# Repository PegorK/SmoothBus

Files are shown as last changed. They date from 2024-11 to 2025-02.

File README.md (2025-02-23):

<div align="center">
  CoverImage
</div>
<p>

# V2 - 2/23/25
<div align="center">
    <table>
        <tr>
            <td>
                <div align="center">
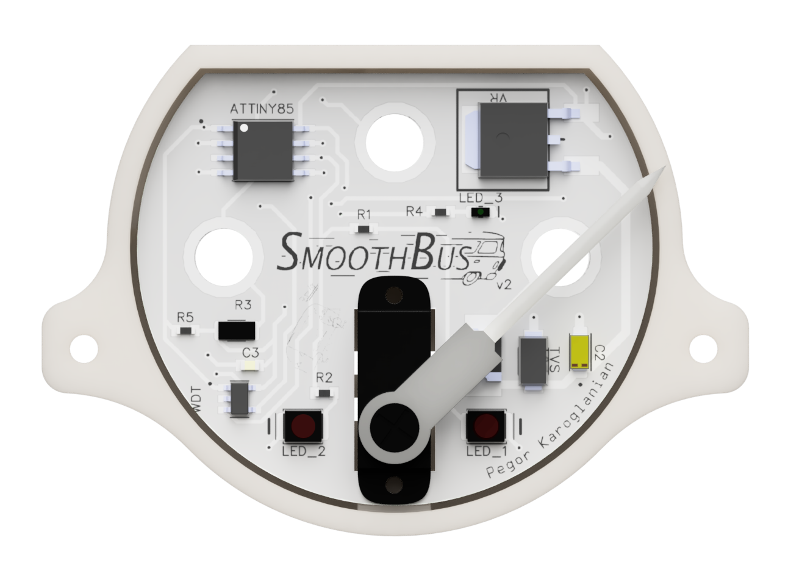
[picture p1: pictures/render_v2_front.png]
V2 Front
                    
                    <br />V2 Front
                </div>
            </td>
            <td>
                <div align="center">
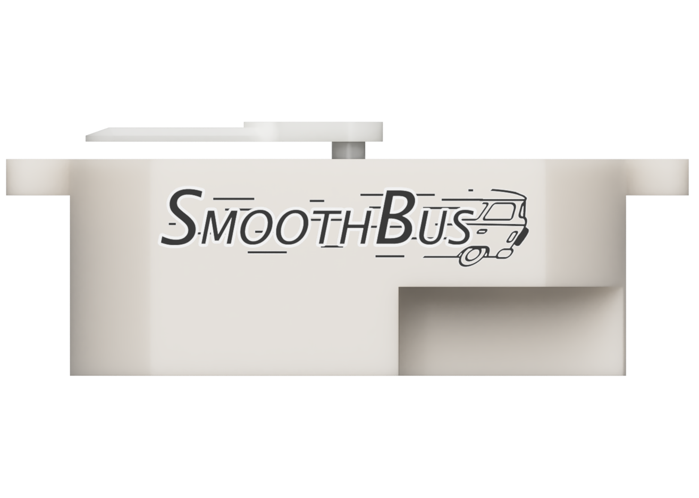
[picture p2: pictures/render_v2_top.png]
V2 Top
                    
                    <br />V2 Top
                </div>
            </td>
            <td>
                <div align="center">
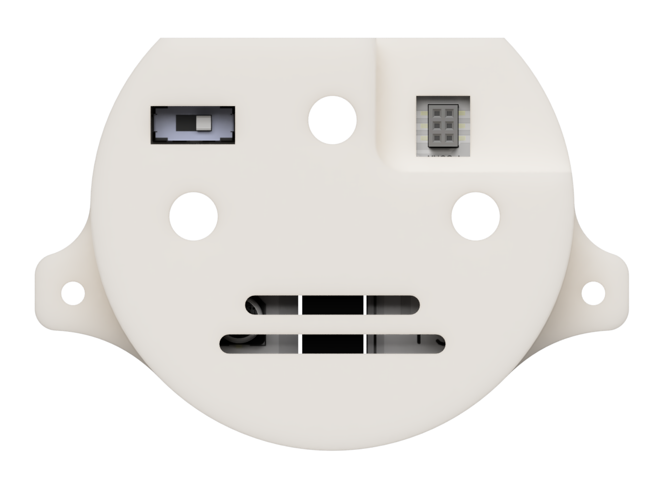
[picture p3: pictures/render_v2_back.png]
V2 Back
                    
                    <br /> V2 Back
                </div>
            </td>
        </tr>
    </table>
</div>

### What's new in V2?
#### Hardware:
* New PCB! Now with input voltage filtering, external watchdog timer, and easier programming connector. 
* Switched to automotive grade ICs (except attiny85, can't find any in stock).
* Reduced voltage divider known resistor value to increase accuracy.
* New 3D printed enclosure to accommodate the new connector, `programming_jig.stl` no longer needed.
#### Software:
* Added new calibration values for fuel sender.
* Added watchdog timer support.
* Increased moving average window size.
* Cleaned up & simplified some chunks of code.
* Removed unused debug.

After getting some feedback on the initial release I decided it was time to put together another build with some improvements that were suggested and also some that I thought would be beneficial. One important change was getting better calibration values from my fuel sender. Previously I was using the data off a forum post that is mentioned below, but I came to realize that my fuel sender (Classic Line 8115800400 from BusDepot) has slightly different readings. I decided to remove it out of the fuel tank and mount it inside a 5 gallon bucket which had lines at the corresponding fuel heights (35mm = R, 75mm = 1/4 tank, 130mm = 1/2 tank, 200mm = Full) and then poured water up to those lines and took multiple readings and averaged them to create the table seen in the code. I left the old values in case it matches someones out there.

In terms of hardware a big improvement is the input voltage filtering, which was completely missing in my original build. Although I didn't run into any power related issues with the first build (at least not for the time I used it), it's better to be safe and this gave me an opportunity to learn a bit more about transient voltages. Speaking of voltages I also upgrade the known resistor R1 in the voltage divider circuit be a lower resistance (50 ohms) and also better rated for the power it's handling. The lower value on this resistor should provide a slightly more accurate reading of the fuel senders position since it's closer to its range. Last new addition I'd like to highlight is the new watchdog timer. I think it's a good failsafe to have in the event there are any funky power glitches that puts the mcu in a bad state. A quick reset from the watchdog in this scenario and we're back up and running and the user wouldn't notice a thing. Hope you enjoy these updates.
<br>
<br>

</p>

<p>

# SmoothBus - 12/4/24
SmoothBus is a fuel gauge conversion for the classic VW Bus. More specifically a 1978 Bus. It's an all in one package with a small form factor that is slightly larger than the original gauge and can be installed with very minimal modifications to the dash. This started as a weekend project after my fuel gauge was showing me readings from all over the place.
</p>
<p>
The original gauges in the buses are pretty clever in design. I've included a picture of it below. It's pretty simple and if my understanding is correct, the flow of current through it causes the wire to heat up and expand which causes the needle to move to different positions. The current is controlled by the fuel sender float which is located in the fuel tank and is essentially a rheostat. Utilizing this thermal property also smooths out bumps and turns since it takes a second or two for it expand & contract. These things don't normally break, it's the voltage regulator that they are connected to that often goes bad, but what's the fun in replacing that when you can make your own.
</p>

<div align="center">
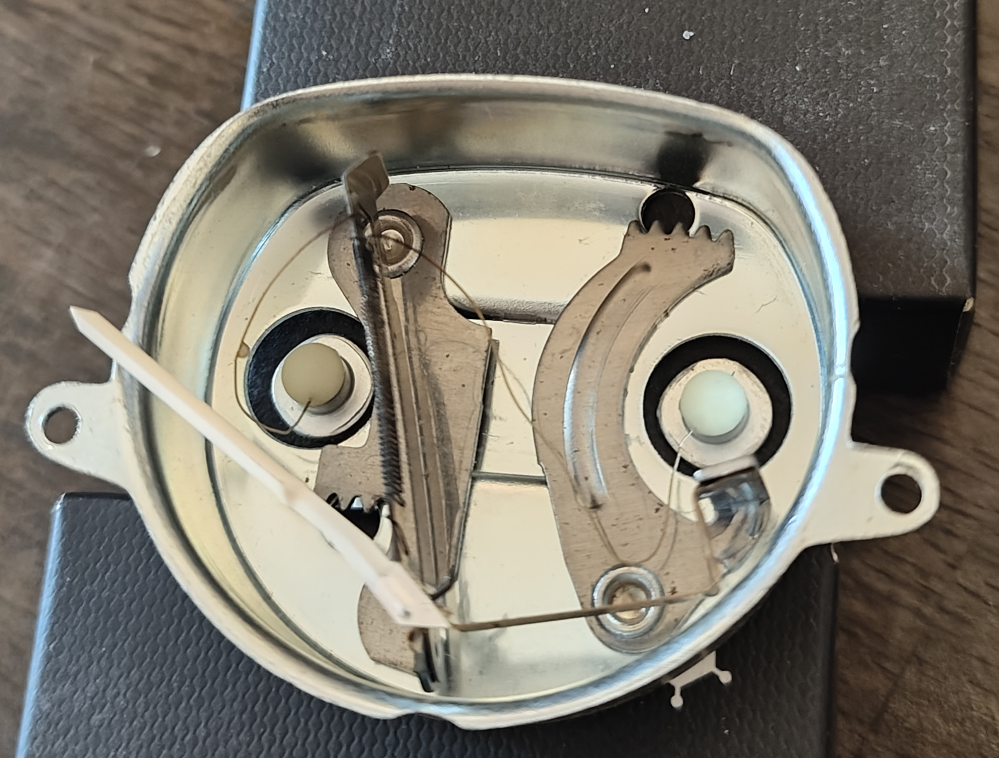
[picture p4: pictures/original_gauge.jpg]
Original fuel gauge
    
    <br />Original fuel gauge guts.
</div>

The SmoothBus design ditches the old gauge components including the voltage regulator keeping only the fuel sender float which is used as the variable resistor in the voltage divider circuit. The overall process is still pretty simple, the ATTiny85 microcontroller reads the analog voltage on one of its input pins and outputs that value as a servo position that corresponds to the location on the original dial. The positions & values were determined by some very useful investigations that were done in this [samba forum post](https://www.thesamba.com/vw/forum/viewtopic.php?t=693930). The analog voltage that gets inputted is the voltage divider circuit that consists of a known resistor value (100ohms) and the unknown resistor value from the fuel sender which ranges from 10 ohms to 79ohms. There is also a moving average that is happening with each read. The configuration that I found works best has been a moving average window of 35 that has readings every 200ms. All of this can be easily changed in the code that can be found in `src` directory. It should be pretty easy to setup, it was all written in the Arduino IDE with the [ATTinyCore](https://github.com/SpenceKonde/ATTinyCore) library that adds support to a bunch of tinyAVR devices (very cool project).

Programming the board wasn't the most intuitive. I decided to have probe points on the board (bottom left corner of PCB) that I thought would be a good idea to easily program the device, but it ended up being a bit finicky. It required making a jig and using tiny spring loaded probes that were then connected to an Arduino Mega that was used as an ISP (see below). [I thought I learned my lesson last time](https://gitlab.com/_Pegor/kepler_fw/-/tree/master/Hardware?ref_type=heads#programming-jig). I think the rest of design is rather straight forward. It contains a voltage regulator that can handle up to 35V and also has some red LEDs to indicate low fuel level. The schematic is included in `hardware/PCB` along with the gerber zip that you can send to a PCB manufacturer of your choice.

<div align="center">
    <table>
        <tr>
            <td>
                <div align="center">
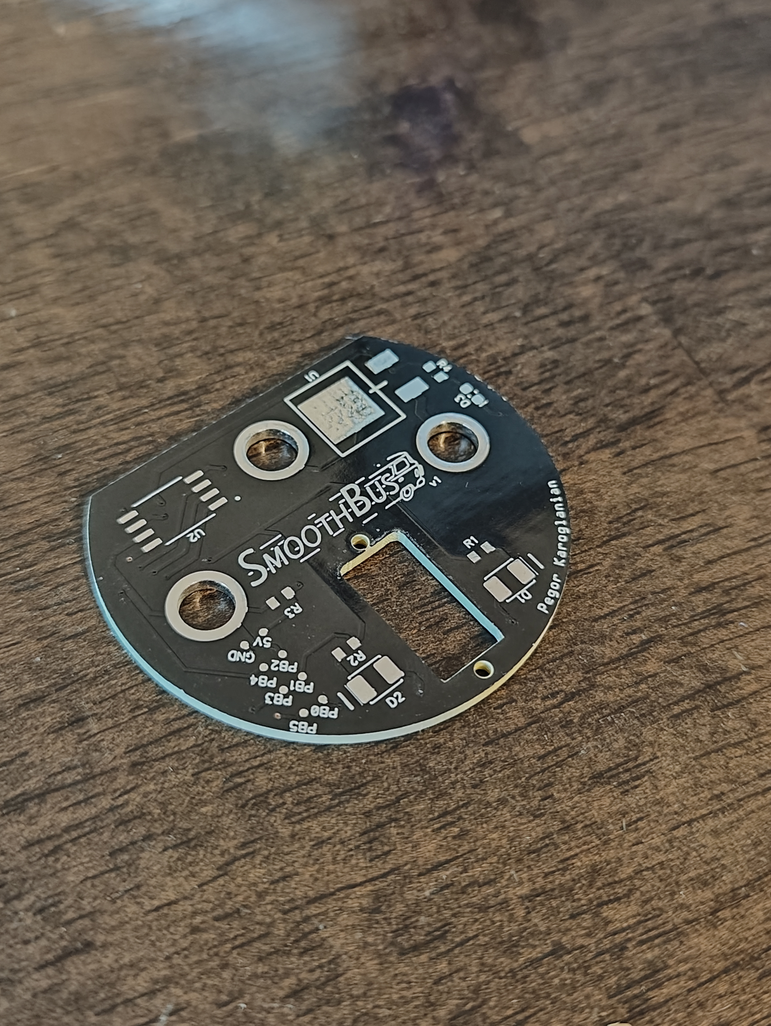
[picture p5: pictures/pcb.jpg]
PCB
                    
                    <br />PCB
                </div>
            </td>
            <td>
                <div align="center">
                    Programming jig
                    <br /> Programming jig
                </div>
            </td>
        </tr>
    </table>
</div>

<div align="center">
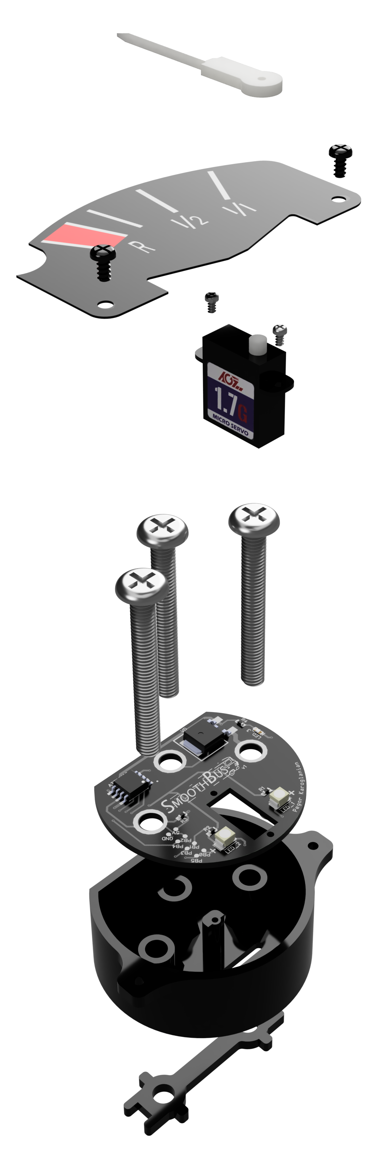
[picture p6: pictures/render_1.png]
Smooth bus render
    
    <br />Render of all the parts.
</div>

I have included all the required 3D parts seen in the render above in the `hardware/3D Parts` directory. Everything was printed in GF-ASA so there is no warping due to warmer temperatures. Installation of the gauge required drilling one hole for the ground screw, other than that there was no other modification required to the dash. You can see it installed below. The red screw is the 12v line, the yellow is for the fuel sender, and the middle is ground, that whole backplate is grounded so no need to run additional wires.

<div align="center">
    <table>
        <tr>
            <td>
                <div align="center">
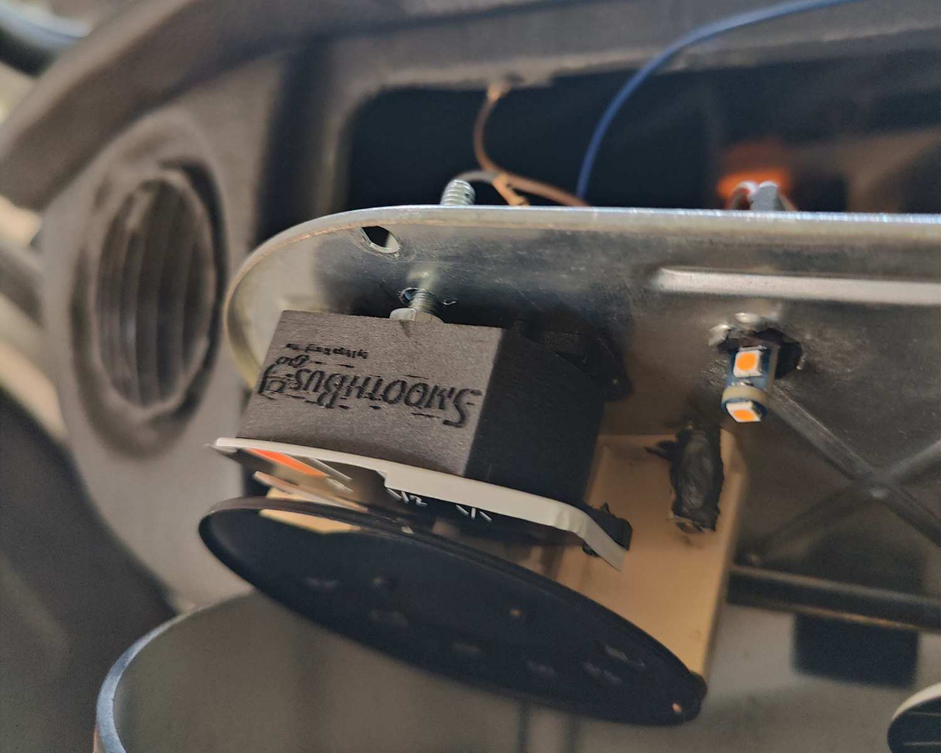
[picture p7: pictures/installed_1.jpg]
Installed Gauge
                    
                    <br />Installed fuel gauge
                </div>
            </td>
            <td>
                <div align="center">
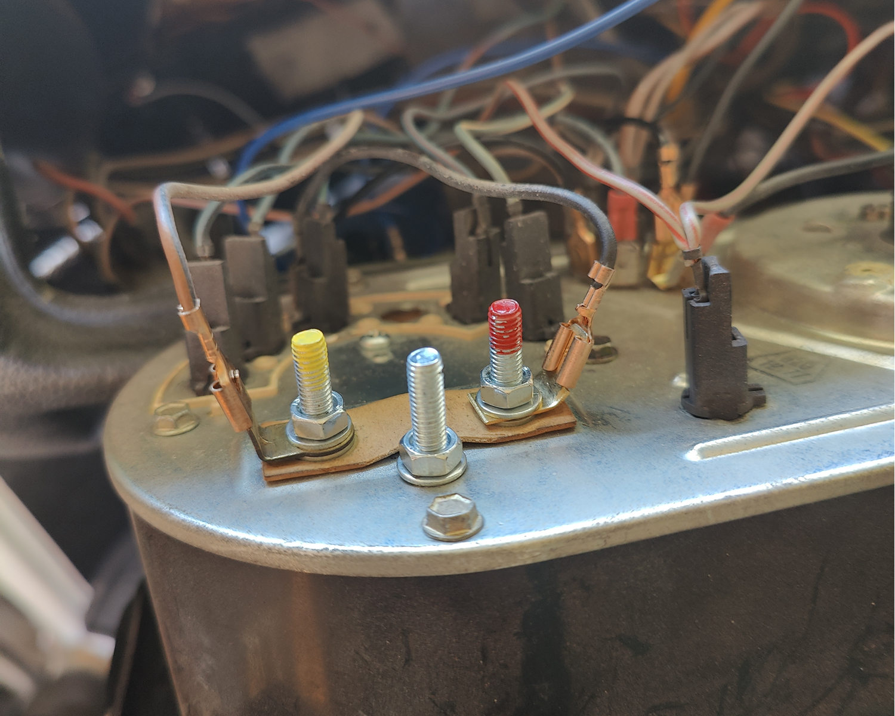
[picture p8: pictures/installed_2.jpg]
Installed Gauge
                    
                    <br /> Terminals of the fuel gauge
                </div>
            </td>
        </tr>
    </table>
</div>

Lastly here is a picture of the finished product and a gif of it in action. Happy tinkering!

<div align="center">
    <table>
        <tr>
            <td>
                <div align="center">
                    SmoothBus Fuel Gauge
                    <br />Complete build
                </div>
            </td>
            <td>
                <div align="center">
                    Installed Gauge
                    <br /> GIF of it in action
                </div>
            </td>
        </tr>
    </table>
</div>
<br>
<br>
Almost forgot! Here is the little loaf if you're curious.
<div align="center">
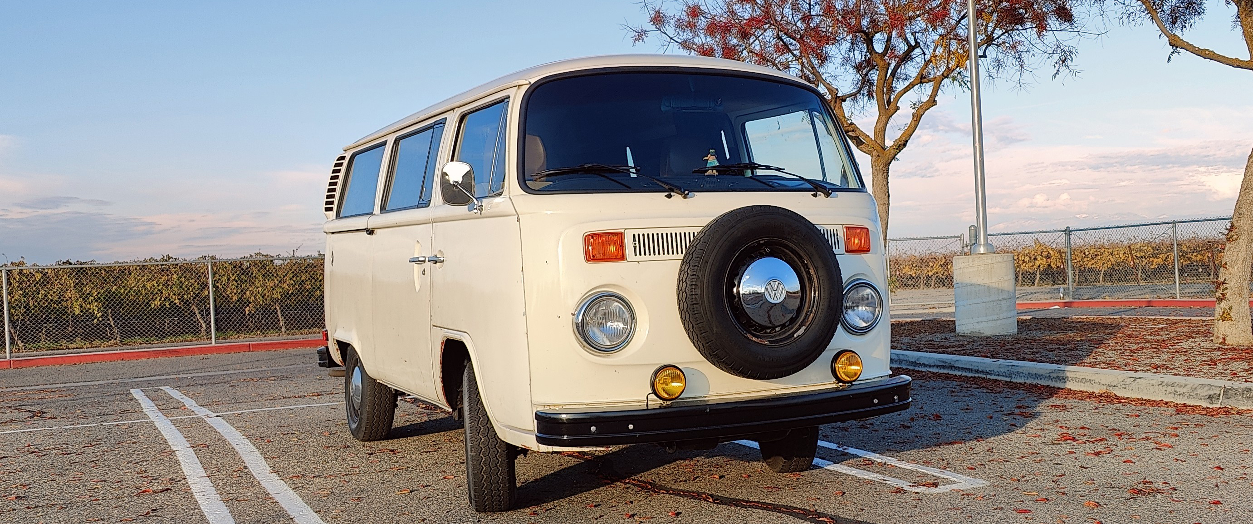
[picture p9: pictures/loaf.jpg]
loaf
  
</div>

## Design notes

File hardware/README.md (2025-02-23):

# SmoothBus Hardware

This folder contains the 3D parts that were used and the PCB components including the schematic.

## 3D Parts

There are 4 total parts that were 3D printed:
* `case.stl`: The housing that the PCB and dial get mounted onto. Printed at standard 0.20mm layer height.
* `hand.stl`: The indicator hand that was then attached to a servo arm. Printed at 0.08mm layer height to preserve the chamfer detail.
* <s>`programming_jig.stl`: The jig that was used along with needle probes to sit on the case and be used to program the MCU. Printed at standard 0.20mm layer height, but the holes didn't come out with the print and I had to drill them by hand with some [REALLY tiny PCB drill bits](https://a.co/d/grPr89h). Resin printing might be better for this piece if possible.</s> No longer needed in V2.
* `spacer.stl`: Required spacer to make sure the connection screws on the back don't short against the metal backplate. Based on the original spacer, but shortened. Printed at standard 0.20mm layer height.

## PCB
* `board_layout_v2_gerber.zip`: Zip file that contains the necessary files to be sent to a PCB manufacturer. This can be directly uploaded to most online manufacturers and should be all you need.
* `smoothbus_v2.pdf`: Schematic that the PCB was based off. 

## Parts list
Most parts were ordered from DigiKey. You can find the link to every part below.
* [ATTiny85 MCU](https://www.digikey.com/short/wmvr7mbd)
* [Voltage Regulator (Automotive Version)](https://www.digikey.com/short/zhz2rd08)
* [Resistor (50Ω)](https://www.digikey.com/short/8h7b4hvm)
* [Resistor (300Ω)](https://www.digikey.com/short/w4hn2znd)
* [Resistor (10kΩ)](https://www.digikey.com/short/w4hn2znd)
* [Capacitor (100uF)](https://www.digikey.com/short/0v2nvz3h)
* [Capacitor (0.33uF)](https://www.digikey.com/short/m4wq48mh)
* [Capacitor (0.1uF)](https://www.digikey.com/short/tbf0djj4)
* [Green LED](https://www.digikey.com/short/ftfzptp3)
* [Red LED](https://a.co/d/7SslF5E)
* [Poly-Fuse](https://www.digikey.com/short/mqrrf4v7)
* [Watchdog Timer](https://www.digikey.com/short/7f4vbqbd)
* [TVS Diode](https://www.digikey.com/short/rtwmwz2c)
* [6 Pos Header](https://www.digikey.com/short/1v5wj33f)
* [SPDT Switch](https://www.digikey.com/short/7v9fw0z2m)
* [Servo](https://a.co/d/cdSHXeV)
* M5 Screws and Nuts (ACE/Home Depot)

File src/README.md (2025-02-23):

# SmoothBus Src

This folder contains the code that gets slapped onto the ATTiny85 chip using the Arduino IDE.

### Dependencies

* [Konde's ATTinyCore library](https://github.com/SpenceKonde/ATTinyCore) - add to your Arduino IDE.

### Flashing

* I used an Arduino Mega2560 as an ISP to flash the ATTiny85. [Here](https://www.instructables.com/How-to-Burn-ATTiny85-Using-Arduino-Mega/) is a decent write up.
    * Flashed the ATTiny85 with the clock set to 16 Mhz, anything less will introduce more servo jitter.

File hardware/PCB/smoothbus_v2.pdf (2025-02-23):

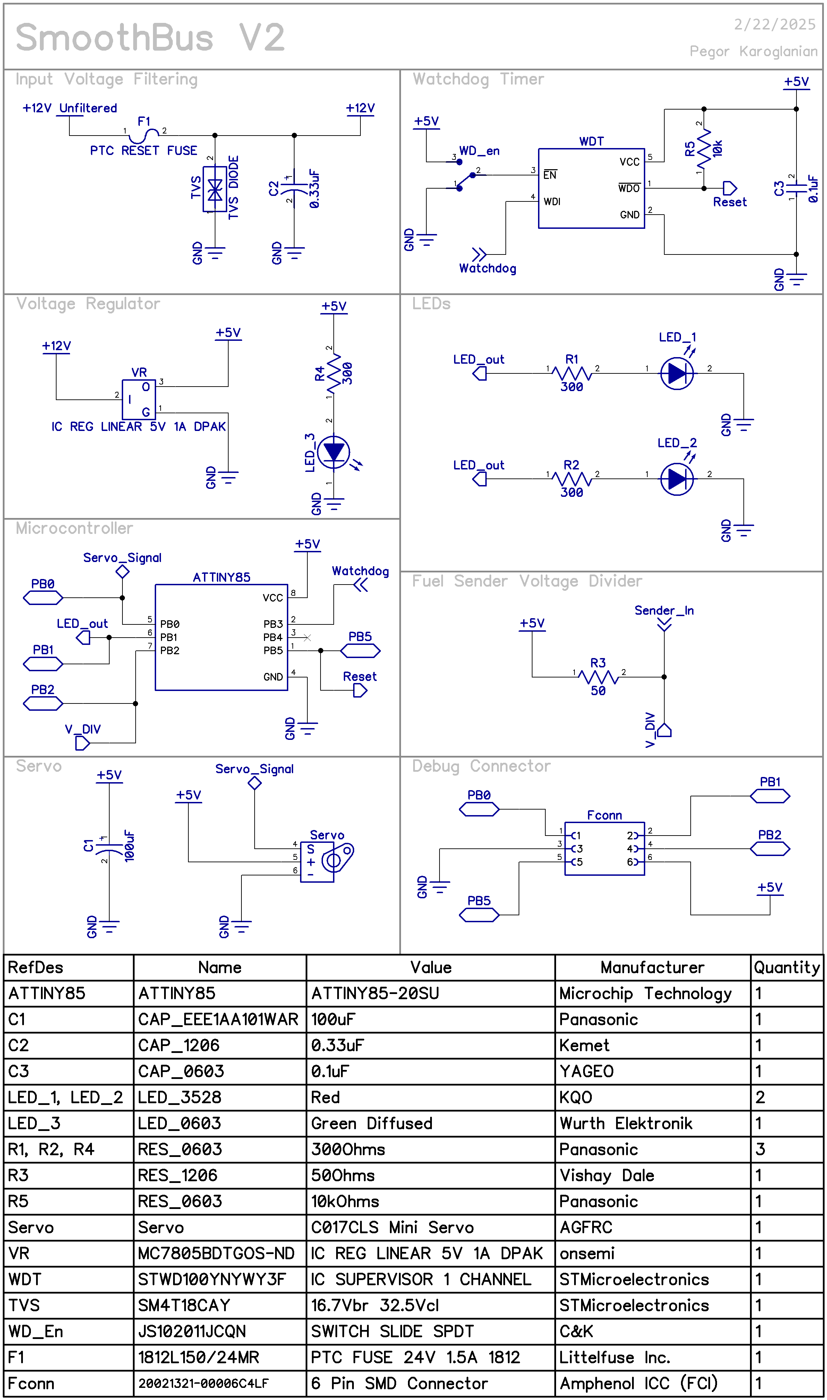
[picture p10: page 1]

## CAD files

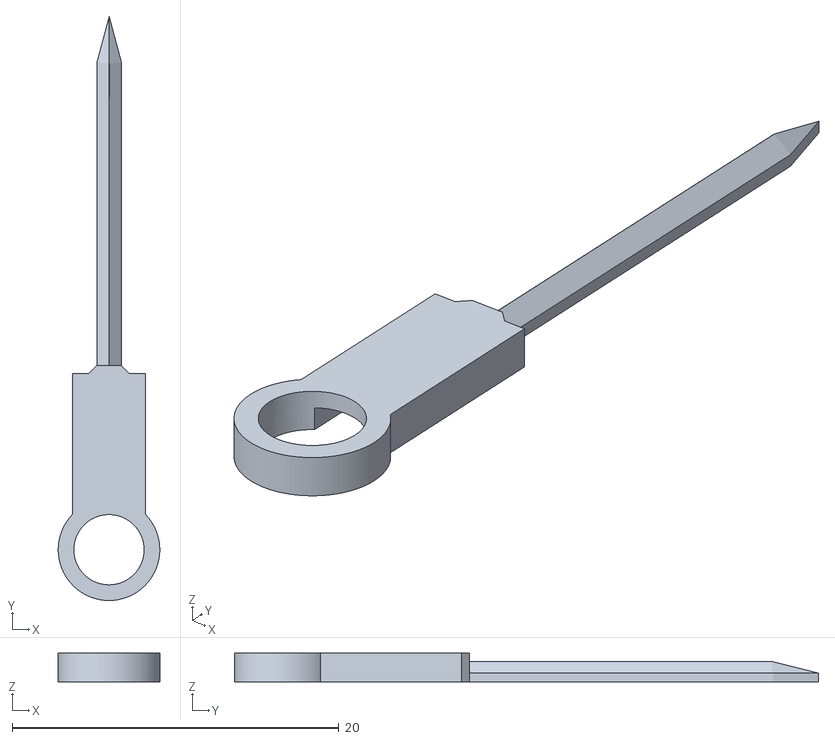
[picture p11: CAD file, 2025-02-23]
hardware/3D Parts/hand.stl
6.22 x 35.8 x 1.75

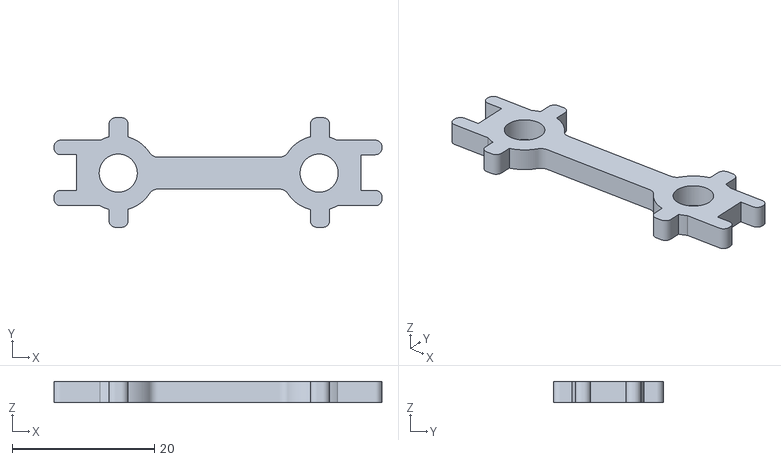
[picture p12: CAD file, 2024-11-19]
hardware/3D Parts/spacer.stl
46.0 x 15.4 x 3.00

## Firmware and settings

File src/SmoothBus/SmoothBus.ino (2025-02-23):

//==========================================
// Title:   SmoothBus.ino
// Author:  Pegor Karoglanian
// Date:    2/22/25
// Notes:   Code for SmoothBus fuel gauge conversion for VW Bus.
// Version: 2.0
//==========================================

#include <Arduino.h>
#include <Servo.h>

#define CLASSIC_LINE_8115800400_SENDER 1

#define SERVO_PIN             0 // (PB0)
#define LOW_FUEL_LED          1 // (PB1)(D1)
#define SENDER_PIN            1 // analog pin (PB2)(A1)
#define WDT_PIN               3 // watchdog time reset pin (PB3)(D3)
#define WDT_PW_US             2 // STWD100YNYWY3F asks at least 1us pulse width.
#define WINDOW_SIZE           70 // window for moving average.
#define READ_DELAY_MS         200 // fuel read frequency
#define SERVO_STEP_DELAY_MS   15 // delay between steps in servo moves for smoother motion
#define INPUT_RESISTANCE      4 // resistance difference measured at sender and dash.
#define R1                    50 // resistor for voltage divider
#define VIN                   5
#define VREF                  5

#if CLASSIC_LINE_8115800400_SENDER
// these resistance values were found by testing my sender
// using a bucket with markings at the corresponding fuel 
// level heights (35mm = R, 75mm = 1/4 tank, 130mm = 1/2 tank, 200mm = Full)
  #define IN_FULL     11
  #define IN_HALF     37
  #define IN_QUARTER  58
  #define IN_R        77
  #define IN_EMPTY    89
#else
// these resistance values are based on info from here:
// https://www.thesamba.com/vw/forum/viewtopic.php?t=693930
  #define IN_FULL     10
  #define IN_HALF     21
  #define IN_QUARTER  33
  #define IN_R        45
  #define IN_EMPTY    79
#endif

// servo position values that matched my setup
#define OUT_FULL      28
#define OUT_HALF      53
#define OUT_QUARTER   74
#define OUT_R         88
#define OUT_EMPTY     102

class SmoothBus {
  private:
    Servo servo;
    int servo_pin;
    int sender_pin;
    int low_fuel_indicator_pin;
    int wdt_pin;
    int raw = 0;

    int servo_pos = OUT_EMPTY;
    int sender_pos = 0;
    int index = 0;
    bool filled = false;
    float avg_arr[WINDOW_SIZE];
    float total = 0;
  
  public:
    SmoothBus(int servo_pin, int sender_pin, int low_fuel_indicator_pin, int wdt_pin) {
      this->servo_pin = servo_pin;
      this->sender_pin = sender_pin;
      this->low_fuel_indicator_pin = low_fuel_indicator_pin;
      this->wdt_pin = wdt_pin;

      init();
    }

    void init() {
      clearWdt();
      pinMode(this->low_fuel_indicator_pin, OUTPUT);
      pinMode(this->wdt_pin, OUTPUT);
      servo.attach(this->servo_pin);
      // only do boot sequence on power up NOT on resets. (WDT)
      if(bit_is_set(MCUSR, PORF)) {
        MCUSR = 0;
        servoBootSequence();
      }
    }

    // sliding boot sequence going from E to Full and back.
    void servoBootSequence() {
      clearWdt();
      servo.write(OUT_EMPTY);
      delay(500);
      clearWdt();
      delay(500);
      clearWdt();
      for (int pos = OUT_EMPTY; pos >= OUT_FULL; pos -= 1) {
        servo.write(pos);
        delay(13);
        clearWdt();
      }
      delay(500);
      for (int pos = OUT_FULL; pos <= OUT_EMPTY; pos += 1) {
        servo.write(pos);
        delay(13);
        clearWdt();
      }
      delay(750);
      clearWdt();
    }

    void readFuelSender() {
      this->raw = analogRead(this->sender_pin);
  
      if (this->raw) {
        float v_out = (this->raw/1023.0) * VREF;
        float fuel_sender = R1 * (v_out/(VIN - v_out));
        fuel_sender -= INPUT_RESISTANCE;

        if (fuel_sender < IN_FULL) {
          fuel_sender = IN_FULL;
        } else if (fuel_sender > IN_EMPTY) {
          fuel_sender = IN_EMPTY;
        }

        int current_avg = round(runningAverage(fuel_sender));

        if (current_avg >= IN_FULL && current_avg <= IN_HALF) { // 1/2 to FULL
          this->sender_pos = mapSenderPos(current_avg, OUT_FULL, OUT_HALF, IN_FULL, IN_HALF);
        } else if (current_avg > (IN_HALF) && current_avg <= IN_QUARTER) { //  1/4 to 1/2
          this->sender_pos = mapSenderPos(current_avg, OUT_HALF, OUT_QUARTER, IN_HALF, IN_QUARTER);
        } else if (current_avg > (IN_QUARTER) && current_avg <= IN_R) { // R to 1/4
          this->sender_pos = mapSenderPos(current_avg, OUT_QUARTER, OUT_R, IN_QUARTER, IN_R);
        } else { // E to R
          this->sender_pos = mapSenderPos(current_avg, OUT_R, OUT_EMPTY, IN_R, IN_EMPTY);
        }
      }
    }

    // map to ranges based on fuel sender calibration data from above forum.
    int mapSenderPos(int current_avg, int out_min, int out_max, int in_min, int in_max) {
       return out_min + (out_max - out_min) * (current_avg - in_min) / (in_max - in_min);
    }

    void updateServoPos() {
      // go in steps instead of shoot to position
      if (this->sender_pos > this->servo_pos) {
        servo.write(this->servo_pos++);
      } else if (this->sender_pos < this->servo_pos) {
        servo.write(this->servo_pos--);
      }

      if (this->servo_pos >= OUT_R ) {
        digitalWrite(this->low_fuel_indicator_pin, HIGH);
      } else if (this->servo_pos < OUT_R) {
        digitalWrite(this->low_fuel_indicator_pin, LOW);
      }
    }

    float runningAverage(float resistance) {
      if (this->filled) {
          this->total -= this->avg_arr[this->index];
      }

      this->avg_arr[this->index] = resistance;
      this->total += resistance;
      this->index = (this->index + 1) % WINDOW_SIZE;

      if (this->index == 0) {
          this->filled = true;
      }

      float running_average = this->total / (this->filled ? WINDOW_SIZE : this->index);
      return running_average;
    }

    void clearWdt() {
      digitalWrite(this->wdt_pin, HIGH);
      delayMicroseconds(WDT_PW_US);
      digitalWrite(this->wdt_pin, LOW);
    }
};

void setup() {
  analogReference(DEFAULT);
}

void loop() {
  SmoothBus smooth_bus(SERVO_PIN, SENDER_PIN, LOW_FUEL_LED, WDT_PIN);
  unsigned long last_read = millis();
  unsigned long last_servo_update = millis();
  while(1) {
    if ((millis() - last_read) >= READ_DELAY_MS) {
      smooth_bus.readFuelSender();
      last_read = millis();
    }

    if ((millis() - last_servo_update) >= SERVO_STEP_DELAY_MS) {
      smooth_bus.updateServoPos();
      last_servo_update = millis();
    }

    smooth_bus.clearWdt();
  }
}

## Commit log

2024-11-19 Add files to project
    [hand.stl, programming_jig.stl, spacer.stl]
2025-02-23 V2 Updates
    [hand.stl, programming_jig.stl]
